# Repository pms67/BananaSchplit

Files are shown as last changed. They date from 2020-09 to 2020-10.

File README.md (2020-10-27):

# Banana Schplit
 **Single rail DC (<12V) to split rail DC supply (+/-12V and +5V).**

Sufficient power capabilities to drive a large amount of analog gear (i.e. op-amps) without needing to perform split-rail biasing and without needing to mess with AC-to-DC power supplies!

---

**Repo contains all design files (KiCad) and production files ready for JLCPCB manufacturing and assembly.**

You can order this board (incl. SMT assembly) at [https://www.jlcpcb.com](https://www.jlcpcb.com).

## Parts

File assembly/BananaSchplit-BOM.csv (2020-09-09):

Value | Designator | Footprint | LCSC Part #
22u | C10,C14 | Capacitor_SMD:C_0805_2012Metric | C45783
8p2 | C11 | Capacitor_SMD:C_0603_1608Metric | C1685
220n | C12 | Capacitor_SMD:C_0603_1608Metric | C21120
4n7 | C13 | Capacitor_SMD:C_0603_1608Metric | C53987
220u | C4 | Capacitor_SMD:CP_Elec_6.3x7.7 | C127327
10u | C1,C3,C5,C6 | Capacitor_SMD:C_1206_3216Metric | C13585
100n | C7 | Capacitor_SMD:C_0603_1608Metric | C14663
10n | C2,C8 | Capacitor_SMD:C_0603_1608Metric | C57112
6p8 | C9 | Capacitor_SMD:C_0603_1608Metric | C1679
B5819W | D1,D2,D3 | Diode_SMD:D_SOD-123 | C8598
RED | D4 | LED_SMD:LED_0805_2012Metric | C84256
GREEN | D5 | LED_SMD:LED_0805_2012Metric | C2297
YELLOW | D6 | LED_SMD:LED_0805_2012Metric | C2296
1A | F1 | Fuse:Fuse_1812_4532Metric | C151168
47u | L1 | SchmillipKiCADLibrary:SWRB1204S | C169398
10u | L2,L3 | Inductor_SMD:L_Sunlord_MWSA0518_5.4x5.2mm | C139506
AO3401A | Q1,Q2 | Package_TO_SOT_SMD:SOT-23 | C15127
12k | R10,R11 | Resistor_SMD:R_0603_1608Metric | C22790
1k5 | R12 | Resistor_SMD:R_0603_1608Metric | C22843
4k3 | R13 | Resistor_SMD:R_0603_1608Metric | C23159
5k1 | R14 | Resistor_SMD:R_0603_1608Metric | C23186
10k | R3 | Resistor_SMD:R_0603_1608Metric | C25804
3k3 | R4 | Resistor_SMD:R_0603_1608Metric | C22978
100 | R5 | Resistor_SMD:R_0603_1608Metric | C22775
1M | R6,R9 | Resistor_SMD:R_0603_1608Metric | C22935
110k | R7 | Resistor_SMD:R_0603_1608Metric | C25805
100k | R1,R2,R8 | Resistor_SMD:R_0603_1608Metric | C25803
TPS5430DDA | U1 | Package_SO:TI_SO-PowerPAD-8_ThermalVias | C9864
TPS65131RGER | U2 | Package_DFN_QFN:QFN-24-1EP_4x4mm_P0.5mm_EP2.6x2.6mm | C87663

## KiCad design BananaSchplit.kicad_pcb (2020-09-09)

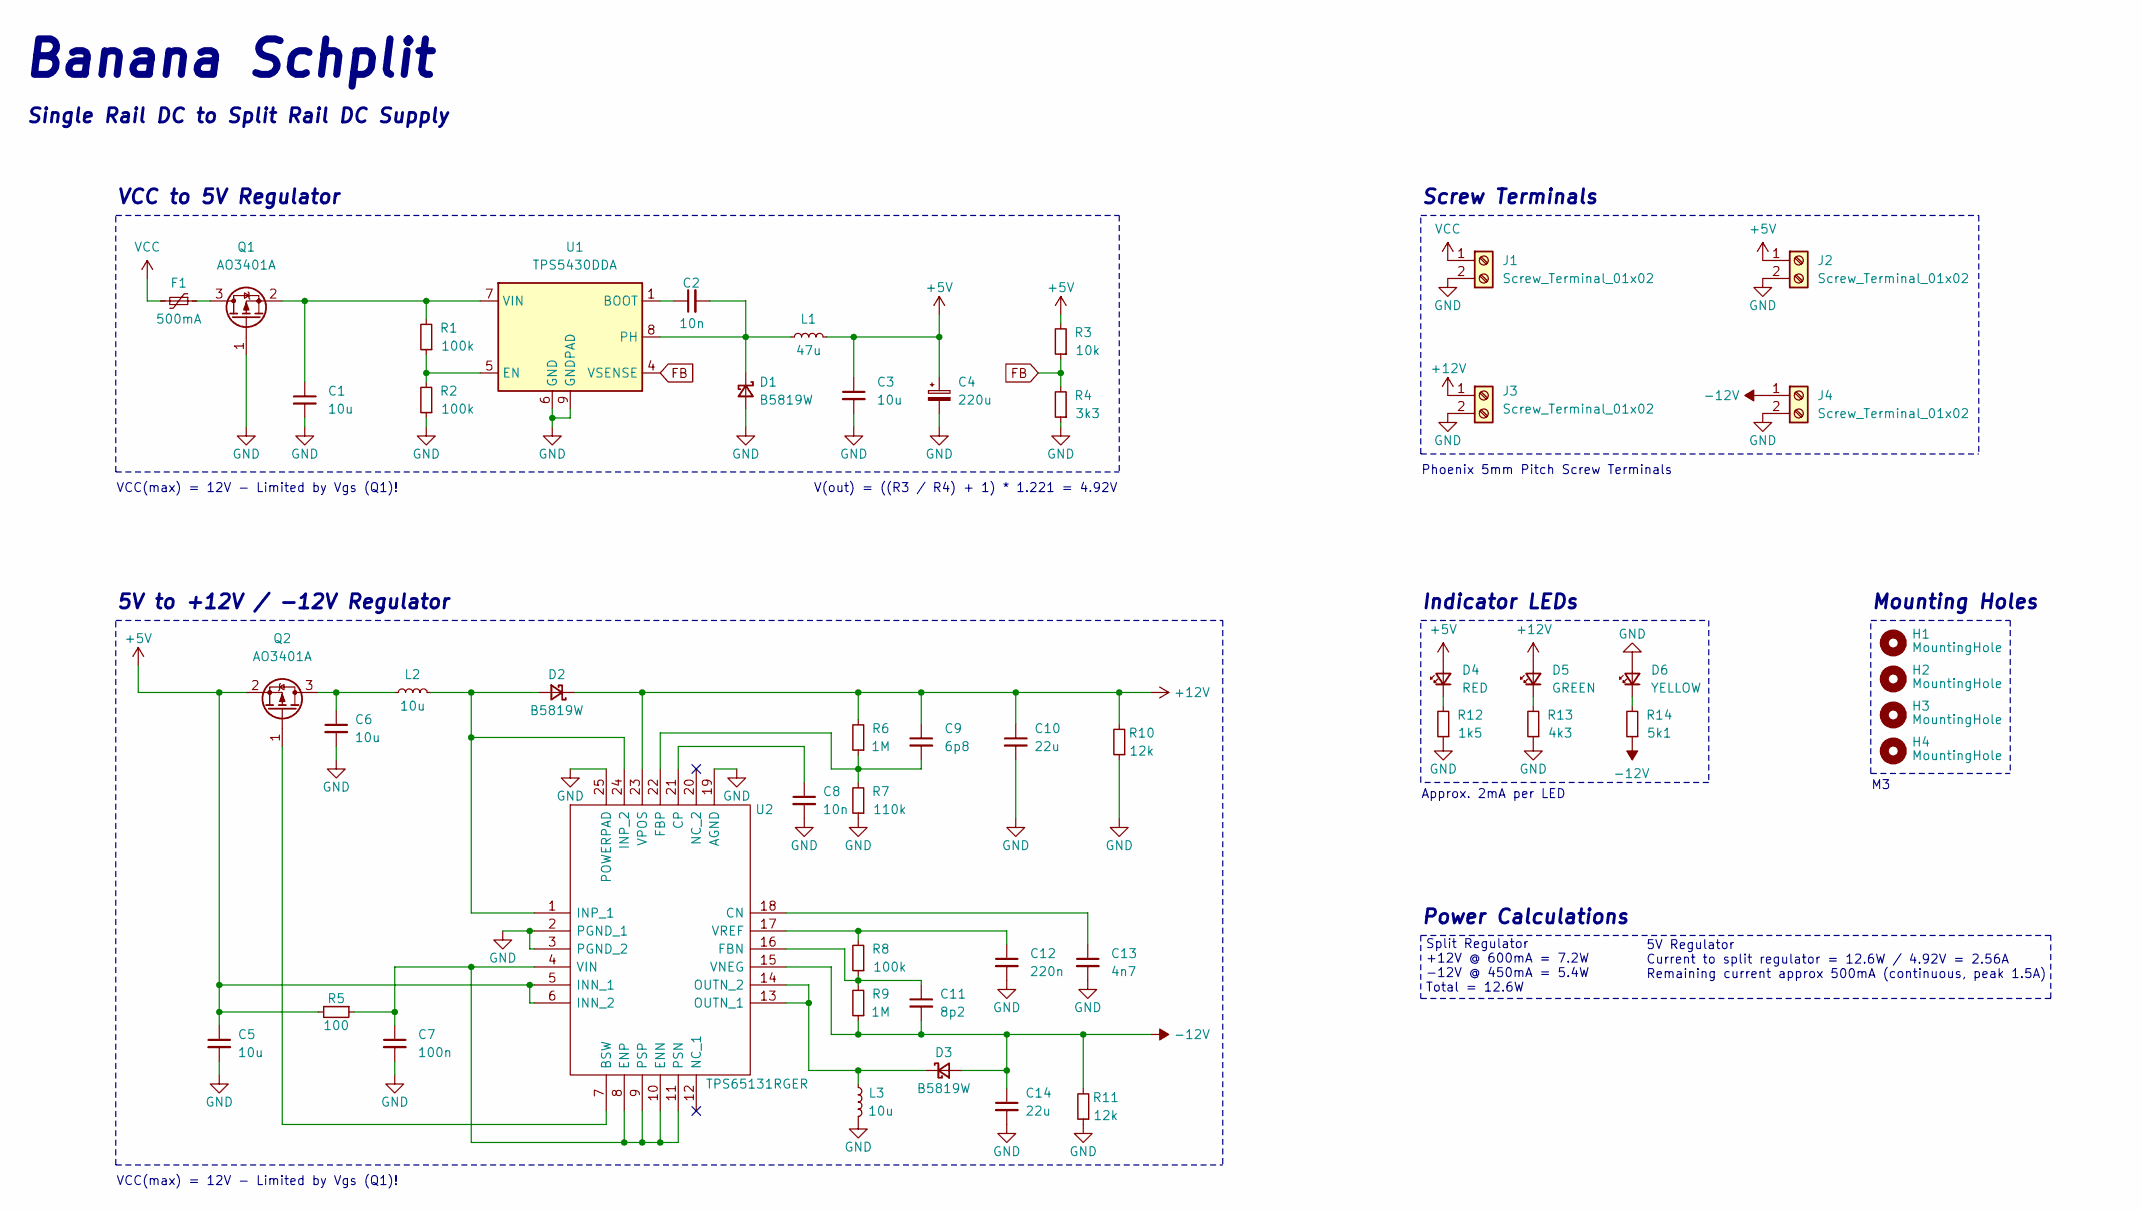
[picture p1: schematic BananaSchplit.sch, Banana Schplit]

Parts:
C1, C3, C5, C6: 10u; C_1206_3216Metric; LCSC Part # C13585
C2, C8: 10n; C_0603_1608Metric; LCSC Part # C57112
C4: 220u; CP_Elec_6.3x7.7; LCSC Part # C127327
C7: 100n; C_0603_1608Metric; LCSC Part # C14663
C9: 6p8; C_0603_1608Metric; LCSC Part # C1679
C10, C14: 22u; C_0805_2012Metric; LCSC Part # C45783
C11: 8p2; C_0603_1608Metric; LCSC Part # C1685
C12: 220n; C_0603_1608Metric; LCSC Part # C21120
C13: 4n7; C_0603_1608Metric; LCSC Part # C53987
D1, D2, D3: B5819W; D_SOD-123; LCSC Part # C8598
D4: RED; LED_0805_2012Metric; LCSC Part # C84256
D5: GREEN; LED_0805_2012Metric; LCSC Part # C2297
D6: YELLOW; LED_0805_2012Metric; LCSC Part # C2296
F1: 500mA; Fuse_1812_4532Metric; LCSC Part # C151168
H1, H2, H3, H4: MountingHole; MountingHole_3.2mm_M3
J1, J2, J3, J4: Screw_Terminal_01x02; TerminalBlock_Phoenix_PT-1,5-2-5.0-H_1x02_P5.00mm_Horizontal
L1: 47u; SWRB1204S; LCSC Part # C169398
L2, L3: 10u; L_Sunlord_MWSA0518_5.4x5.2mm; LCSC Part # C139506
Q1, Q2: AO3401A; SOT-23; LCSC Part # C15127
R1, R2, R8: 100k; R_0603_1608Metric; LCSC Part # C25803
R3: 10k; R_0603_1608Metric; LCSC Part # C25804
R4: 3k3; R_0603_1608Metric; LCSC Part # C22978
R5: 100; R_0603_1608Metric; LCSC Part # C22775
R6, R9: 1M; R_0603_1608Metric; LCSC Part # C22935
R7: 110k; R_0603_1608Metric; LCSC Part # C25805
R10, R11: 12k; R_0603_1608Metric; LCSC Part # C22790
R12: 1k5; R_0603_1608Metric; LCSC Part # C22843
R13: 4k3; R_0603_1608Metric; LCSC Part # C23159
R14: 5k1; R_0603_1608Metric; LCSC Part # C23186
U1: TPS5430DDA; TI_SO-PowerPAD-8_ThermalVias; LCSC Part # C9864
U2: TPS65131RGER; QFN-24-1EP_4x4mm_P0.5mm_EP2.6x2.6mm; Mouser2 Part Number 595-TPS65131RGET

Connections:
+5V: C3.1, C4.1, C5.1, D4.2 (A), J2.1, L1.2, Q2.2 (S), R3.2, R5.2, U2.5 (INN_1), U2.6 (INN_2)
+12V: C9.1, C10.1, D2.1 (K), D5.2 (A), J3.1, R6.2, R10.2, U2.23 (VPOS)
-12V: C11.2, C14.1, D3.2 (A), J4.1, R9.1, R11.2, R14.1, U2.15 (VNEG)
FB: R3.1, R4.2, U1.4 (VSENSE)
GND: C1.2, C3.2, C4.2, C5.2, C6.2, C7.2, C8.2, C10.2, C12.2, C13.2, C14.2, D1.2 (A), D6.2 (A), J1.2, J2.2, J3.2, J4.2, L3.2, Q1.1 (G), R2.1, R4.1, R7.1, R10.1, R11.1, R12.1, R13.1, U1.6 (GND), U1.9 (GNDPAD), U2.2 (PGND_1), U2.3 (PGND_2), U2.19 (AGND), U2.25 (POWERPAD)
unnamed: C1.1, Q1.2 (S), R1.2, U1.7 (VIN)
unnamed: C2.1, U1.1 (BOOT)
unnamed: C2.2, D1.1 (K), L1.1, U1.8 (PH)
unnamed: C6.1, L2.1, Q2.3 (D)
unnamed: C7.1, R5.1, U2.4 (VIN), U2.8 (ENP), U2.9 (PSP), U2.10 (ENN), U2.11 (PSN)
unnamed: C8.1, U2.21 (CP)
unnamed: C9.2, R6.1, R7.2, U2.22 (FBP)
unnamed: C11.1, R8.1, R9.2, U2.16 (FBN)
unnamed: C12.1, R8.2, U2.17 (VREF)
unnamed: C13.1, U2.18 (CN)
unnamed: D2.2 (A), L2.2, U2.1 (INP_1), U2.24 (INP_2)
unnamed: D3.1 (K), L3.1, U2.13 (OUTN_1), U2.14 (OUTN_2)
unnamed: D4.1 (K), R12.2
unnamed: D5.1 (K), R13.2
unnamed: D6.1 (K), R14.2
unnamed: F1.1, Q1.3 (D)
unnamed: Q2.1 (G), U2.7 (BSW)
unnamed: R1.1, R2.2, U1.5 (EN)
VCC: F1.2, J1.1

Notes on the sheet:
VCC to 5V Regulator
5V to +12V / -12V Regulator
Screw Terminals
Indicator LEDs
Mounting Holes
Banana Schplit
Single Rail DC to Split Rail DC Supply
VCC(max) = 12V - Limited by Vgs (Q1)!
V(out) = ((R3 / R4) + 1) * 1.221 = 4.92V
Phoenix 5mm Pitch Screw Terminals
Approx. 2mA per LED
Split Regulator +12V @ 600mA = 7.2W -12V @ 450mA = 5.4W Total = 12.6W
5V Regulator Current to split regulator = 12.6W / 4.92V = 2.56A Remaining current approx 500mA (continuous, peak 1.5A)
Power Calculations

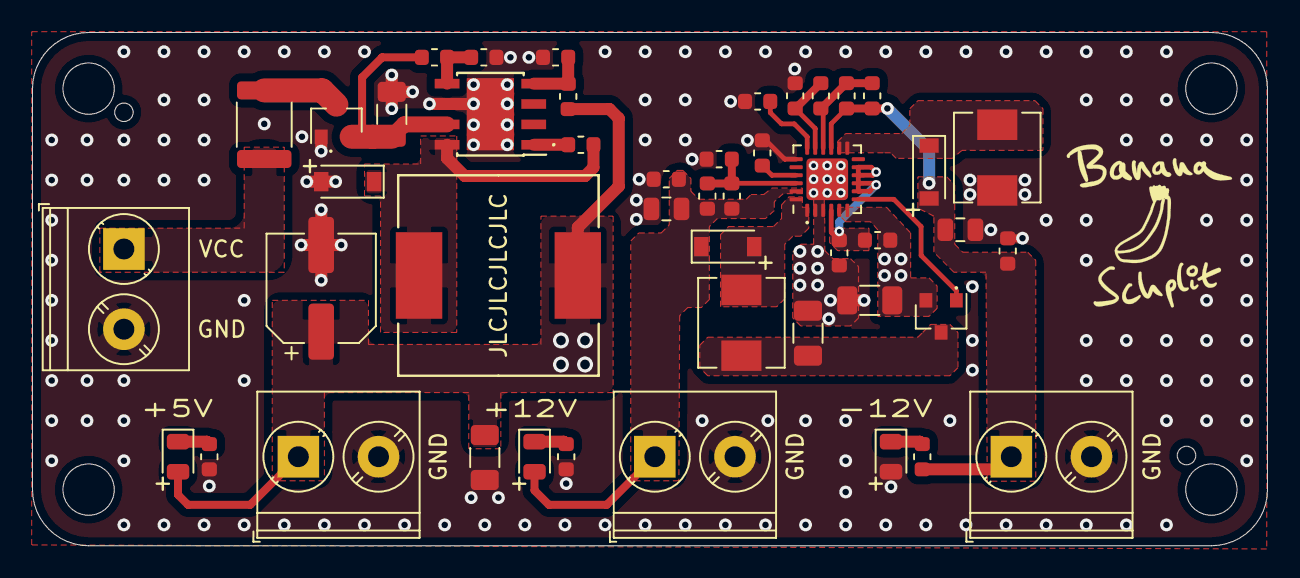
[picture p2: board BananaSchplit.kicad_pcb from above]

Board: 2 copper layers, 77.0 x 32.0 mm, 50 parts (0 on the bottom side), 24 nets.

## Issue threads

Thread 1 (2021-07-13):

D1 Catch Diode Selection - I_f(avg) too low?

M4a1x, 2021-07-13:
Hey Phil,

first off: Thanks for the great videos they have been an immense help! I found this board looking for inspirations on the [TPS5430](https://datasheet.lcsc.com/lcsc/1811081920_Texas-Instruments-TPS5430DDAR_C9864.pdf) 5V/3A power supply, since it's a basic part at JLCPCB.

I noticed that in your design for D1 (didn't look at the split rail regulator) you went with a [B5819W](https://datasheet.lcsc.com/lcsc/1809140216_Changjiang-Electronics-Tech-CJ-B5819W_C8598.pdf) 0.6V/1A (max. 40V reverse) Schottky diode, whereas TI suggests in the datasheet (Chapter 8.2.1.2.6) a [B340A](https://datasheet.lcsc.com/lcsc/1810251611_Diodes-Incorporated-B340A-13-F_C85098.pdf) 0.5V/3A (max. 40V reverse) for their 5V supply, as it "must be greater than I_out".

Since you specified your load to be max. 2.5A I think the Diode might be running out of spec on high loads. I was wondering if e.g. an [SS34](https://datasheet.lcsc.com/lcsc/2105061435_MDD-Microdiode-Electronics-SS34_C8678.pdf) (also a basic part) would be a better choice.

I'm no professional though, so if your choice was deliberate I would love to hear about the calculations to understand this better. On this remark, I would love to hear the reasoning why you didn't "just copy" the values from the "Typical Application" of the datasheet (Chapter 8.2.1) - e.g. the 47uH inductor vs the suggested 15uH - if you still remember after all this time.

Thanks for reading :)

Cheers,
Max

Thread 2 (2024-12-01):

Please Add Link to Your YouTube Video on This Design

ForrestErickson, 2024-12-01:
I frequently refer people to your work and think this is a nice example but I have to search to find your Youtube video on this design and today, 20241201 I cannot find it.

Please add to your README.md a link to your youtube video.

ForrestErickson, 2024-12-01:
Found it by googling "Phil's lab "BananaSchplit" video" which took me to here: https://www.eevblog.com/forum/beginners/split-powersupply-(banana-schplit)-issues-with-negative-12v-rail/

The video:
https://youtu.be/qXWYXxDokv4?si=MYj0MRngGSbCeOmj
